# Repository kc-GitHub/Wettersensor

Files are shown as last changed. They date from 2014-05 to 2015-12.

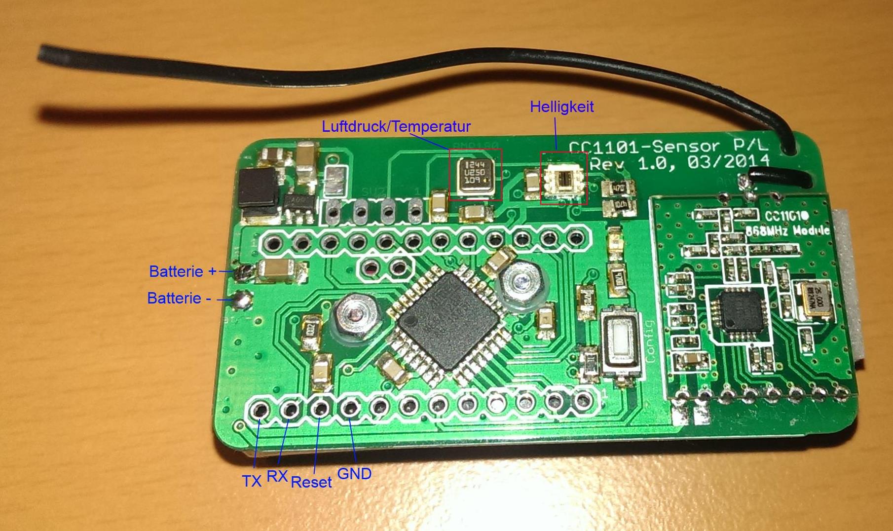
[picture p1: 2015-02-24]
Images/HB-UW-Sen-THPL-O_Overview_Rev_1.0.jpg

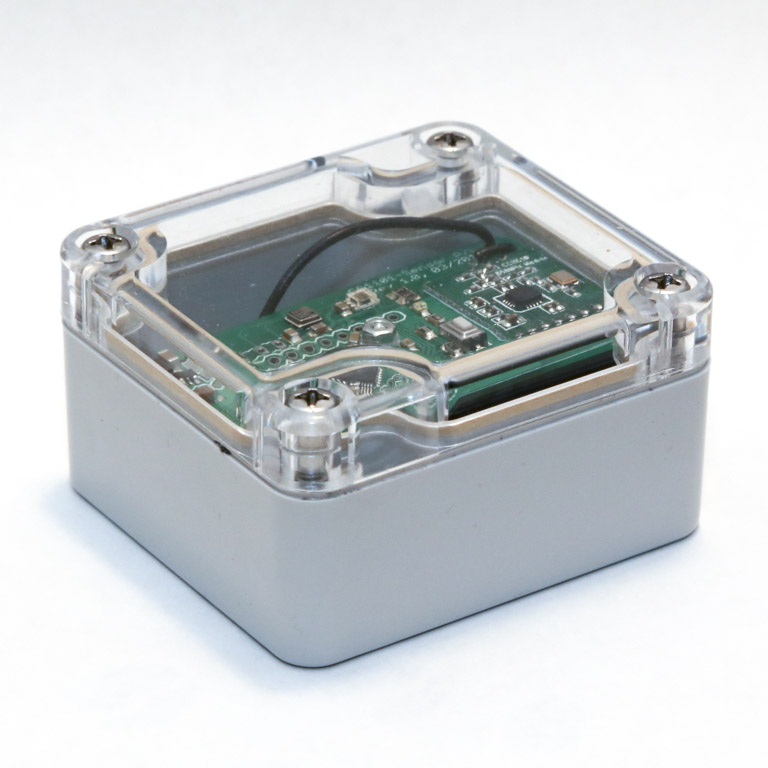
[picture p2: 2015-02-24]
Images/HB-UW-Sen-THPL-O.jpg

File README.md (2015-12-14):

Firmware for Univarsal Wettersensor
===================================

* http://www.fhemwiki.de/wiki/Universalsensor
* http://forum.fhem.de/index.php/topic,20620.0.html

#Changelog#

##Version 0.15 (Development)##
 * Improve / Fix debugging.
 * Fix [#16](/../../issues/16) so peering with HM-CC-RT-DN should stable now.
 * Add hysteresis for battery voltage measurement.
 * Experimental support for US-100 ultrasonic distance sensor (Do not use this experimental feature if you need the peering with HM-CC-RT-DN at this time)

##Version 0.14##
 * Fix millis() overflow bug. Now, the sensor stays in sleep mode after 49 days, so battery should not drained anymore
 * Battery voltage now measured with 1 digit only.

##Version 0.13 (Beta)##
 * Add new register:
   - transmitTryMax: How often should the sensor try to send data without ack.
   - lowBatLimit: Defined the battery voltage used for low battery detection.
   - ledMode: Switch the device LED on or off while sent out data.
   - altitude: Define the sensor-altitude for calculating the air pressure at sea level.

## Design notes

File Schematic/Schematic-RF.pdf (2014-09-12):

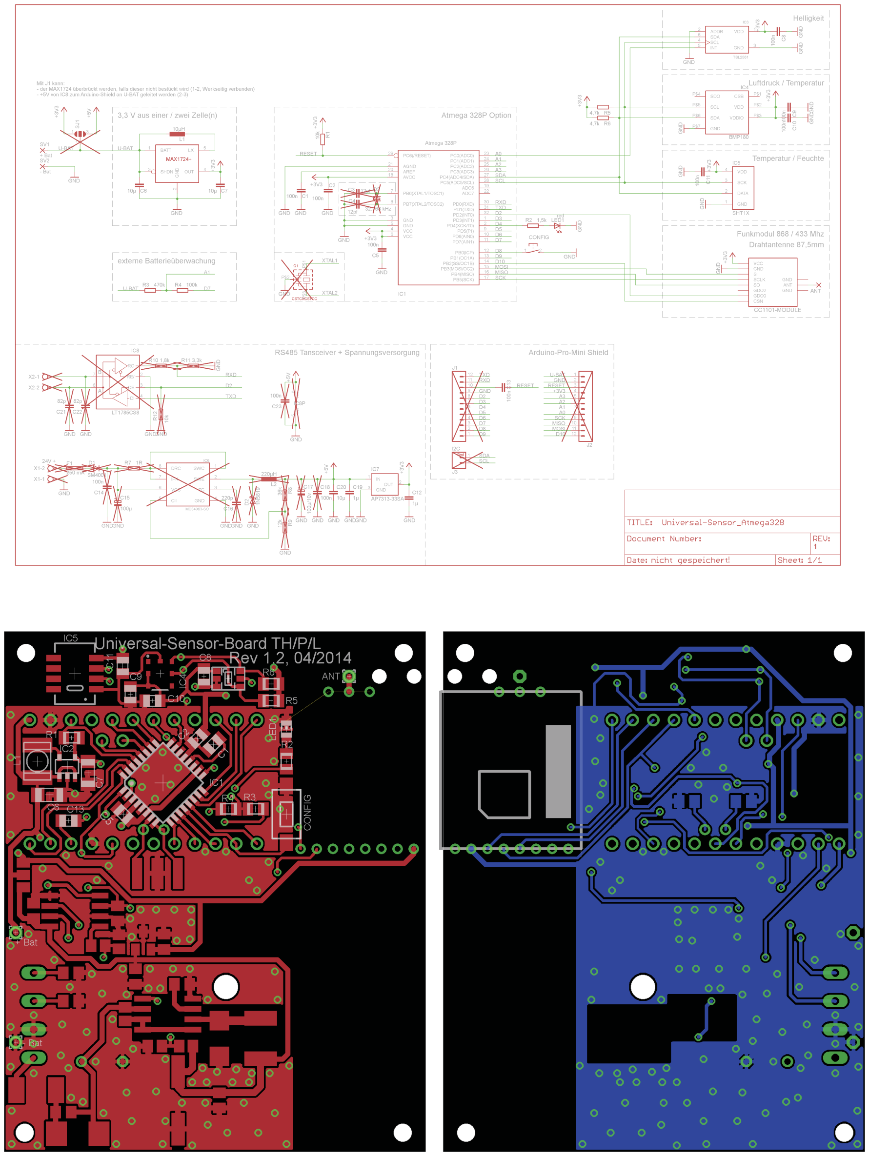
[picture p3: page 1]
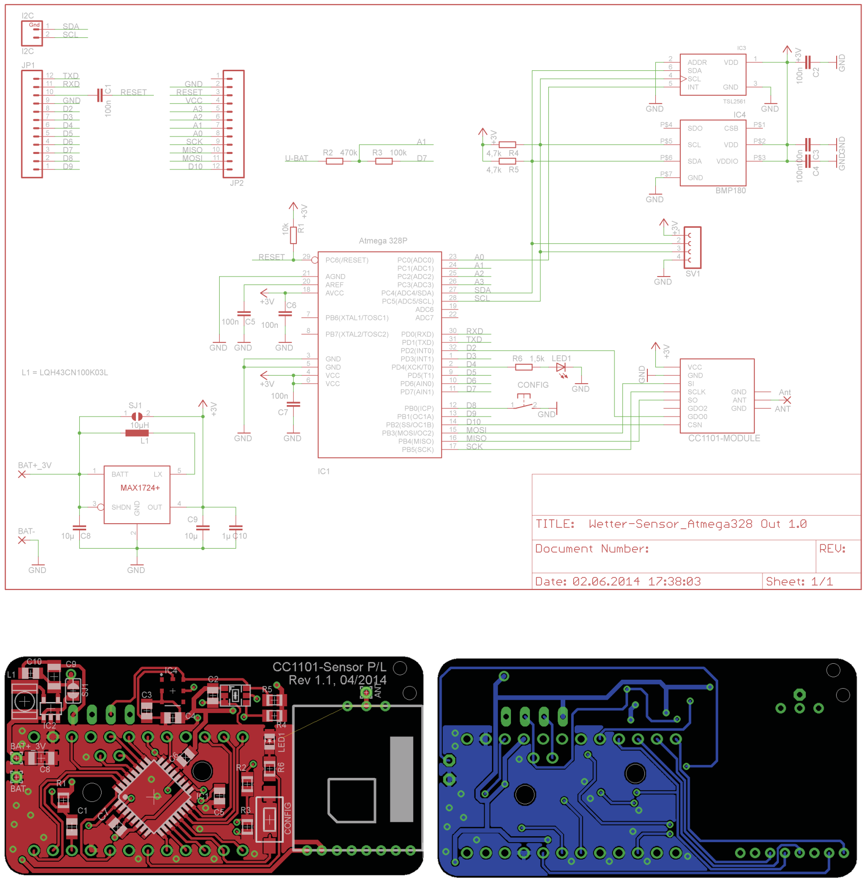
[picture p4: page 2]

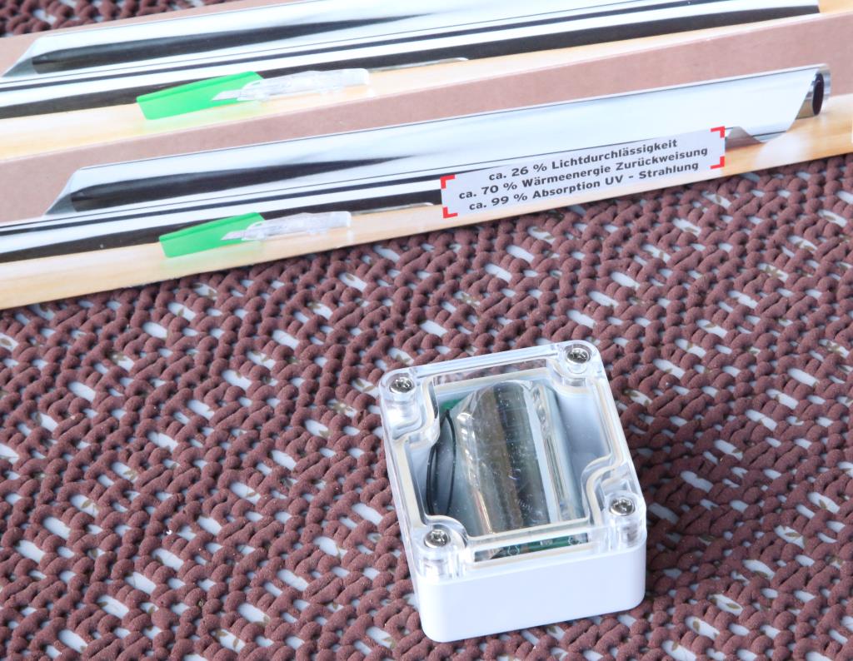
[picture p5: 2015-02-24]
Images/HB-UW-Sen-THPL-O_filter_foil.JPG

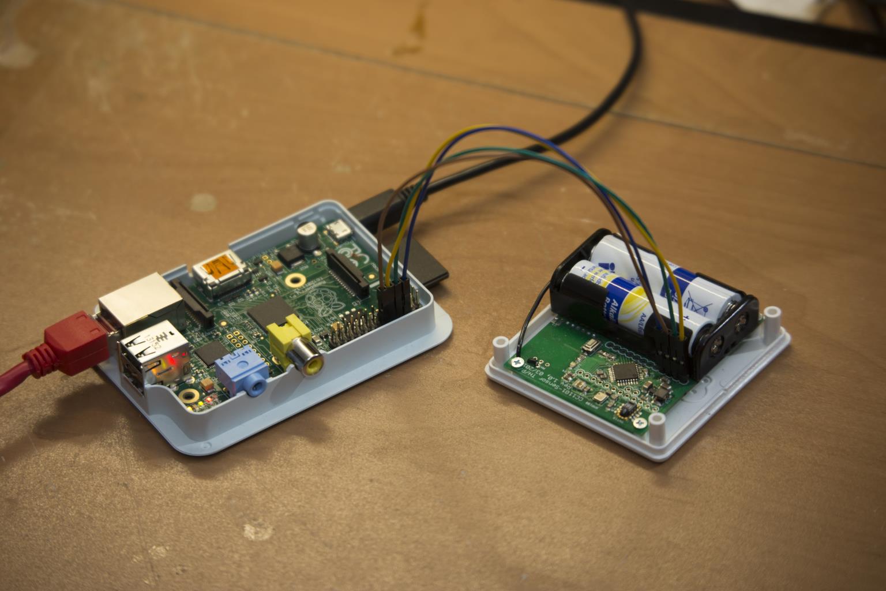
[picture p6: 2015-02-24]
Images/CC1101-Sensor Firmwareupdate mit dem Raspberry Pi.jpg

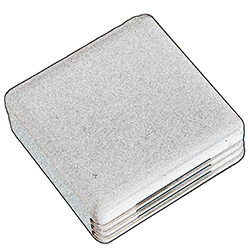
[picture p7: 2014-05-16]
Contrib/CCU/HB-UW-Sen-THPL_CCU-addon-src/www/config/img/devices/250/hb-uw-sen-thpl-i.png

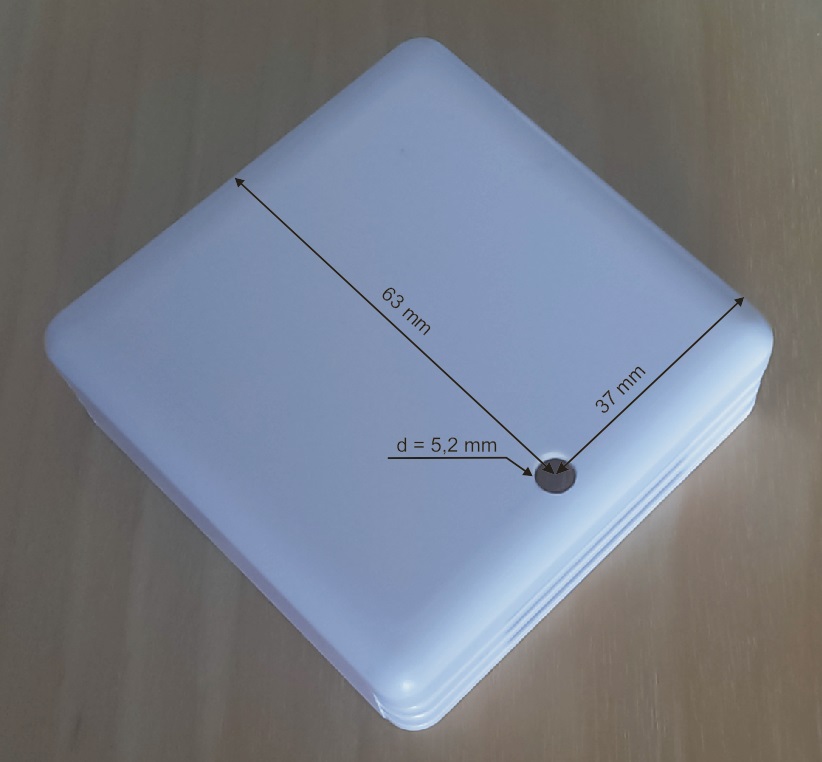
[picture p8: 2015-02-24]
Images/HB-UW-Sen-THPL-drill_dimension.jpg

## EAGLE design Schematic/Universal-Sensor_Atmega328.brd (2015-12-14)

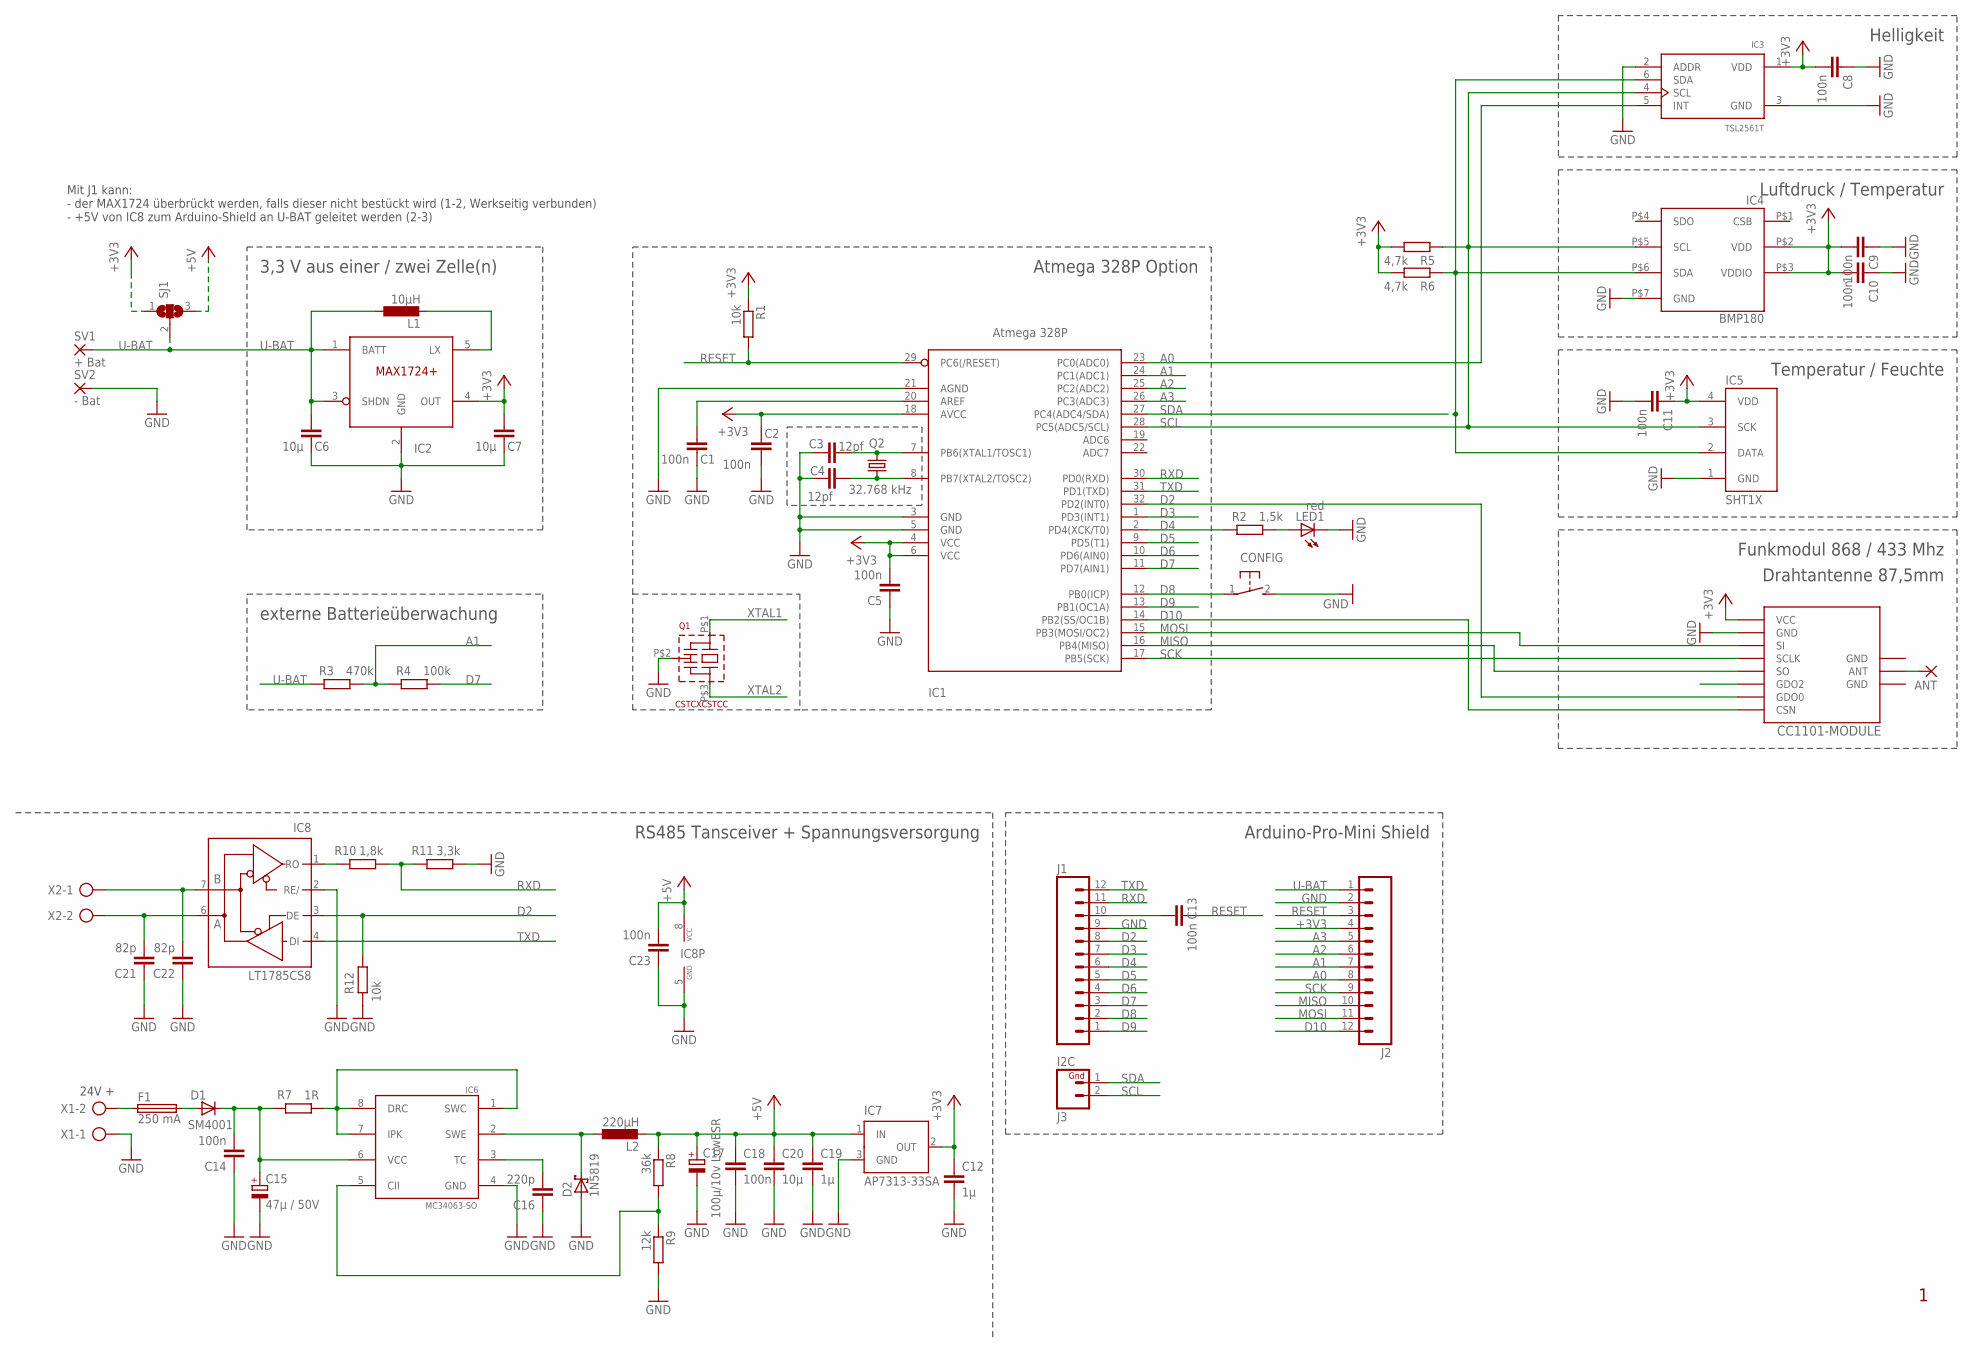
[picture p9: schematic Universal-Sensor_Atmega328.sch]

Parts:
ANT: 1,6/0,8
C1, C2, C5, C8, C9, C10, C11, C13, C18, C23: 100n; C0805
C3, C4: 12pf; C0805
C6, C7, C20: 10µ; C1206
C12, C19: 1µ; C0805
C14: 100n; C1206
C15: 47µ / 50V; E2,5-7
C16: 220p; C0805
C17: 100µ/10v LowESR; SMC_D
C21, C22: 82p; C0805
CC1101-MODULE: CC1101_WIRELES_MODULE
CONFIG: DTSM-3
D1: SM4001; MELF-MLL41
D2: 1N5819; SMB
F1: 250 mA; SMD-6,1X2,6
IC1: Atmega 328P; TQFP32-08
IC2: MAX1724; SOT23-5L
IC3: TSL2561T; TMB-6
IC4: BMP180; LGA-7
IC5: SHT1X
IC6: MC34063-SO; SO8
IC7: AP7313-33SA; SOT23
IC8: LT1785CS8; SO08
J1, J2: M12PTH; 1X12
J3: I2C; 1X02
L1: 10µH; L4532P
L2: 220µH; L5650M
LED1: red; CHIP-LED0805
Q1: CSTCXCSTCC; CSTCC
Q2: 32.768 kHz; TC38H
R1, R12: 10k; M0805
R2: 1,5k; M0805
R3: 470k; M0805
R4: 100k; M0805
R5, R6: 4,7k; M0805
R7: 1R; R0805
R8: 36k; R0805
R9: 12k; R0805
R10: 1,8k; R0805
R11: 3,3k; R0805
SJ1: SJ2W; SJ_2
SV1: + Bat; 1,6/0,9
SV2: - Bat; 1,6/0,9
X1, X2: AK550/2

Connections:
+3V3: C2.2, C5.2, C7.2, C8.2, C9.2, C10.2, C11.1, C12.1, CC1101-MODULE.VCC, IC1.4 (VCC), IC1.6 (VCC), IC1.18 (AVCC), IC2.4 (OUT), IC3.1 (VDD), IC4.P$2 (VDD), IC4.P$3 (VDDIO), IC5.4 (VDD), IC7.2 (OUT), J2.4, R1.1, R5.2, R6.2, SJ1.1
+5V: C17.+, C18.1, C19.1, C20.1, C23.2, IC7.1 (IN), IC8.8 (VCC), L2.2, R8.1, SJ1.3
A: C21.2, IC8.6 (A), X2.2
A0: IC1.23 (PC0(ADC0)), IC3.5 (INT), J2.8
A1: IC1.24 (PC1(ADC1)), J2.7, R3.2, R4.1
A2: IC1.25 (PC2(ADC2)), J2.6
A3: IC1.26 (PC3(ADC3)), J2.5
B: C22.2, IC8.7 (B), X2.1
D2: CC1101-MODULE.GDO0, IC1.32 (PD2(INT0)), IC8.3 (DE), J1.8, R12.2
D3: IC1.1 (PD3(INT1)), J1.7
D4: IC1.2 (PD4(XCK/T0)), J1.6, R2.1
D5: IC1.9 (PD5(T1)), J1.5
D6: IC1.10 (PD6(AIN0)), J1.4
D7: IC1.11 (PD7(AIN1)), J1.3, R4.2
D8: CONFIG.1, IC1.12 (PB0(ICP)), J1.2
D9: IC1.13 (PB1(OC1A)), J1.1
D10: CC1101-MODULE.CSN, IC1.14 (PB2(SS/OC1B)), J2.12
GND: C1.1, C2.1, C3.2, C4.2, C5.1, C6.1, C7.1, C8.1, C9.1, C10.1, C11.2, C12.2, C14.1, C15.-, C16.1, C17.-, C18.2, C19.2, C20.2, C21.1, C22.1, C23.1, CC1101-MODULE.GND@1 (GND), CC1101-MODULE.GND@2 (GND), CC1101-MODULE.GND@3 (GND), CONFIG.2, D2.A, IC1.3 (GND), IC1.5 (GND), IC1.21 (AGND), IC2.2 (GND), IC3.2 (ADDR), IC3.3 (GND), IC4.P$7 (GND), IC5.1 (GND), IC6.4 (GND), IC7.3 (GND), IC8.2 (RE/), IC8.5 (GND), J1.9, J2.2, LED1.C, Q1.P$2 (GND), R9.2, R11.1, R12.1, SV2.1, X1.1
MISO: CC1101-MODULE.SO, IC1.16 (PB4(MISO)), J2.10
MOSI: CC1101-MODULE.SI, IC1.15 (PB3(MOSI/OC2)), J2.11
unnamed: C13.2, J1.10
unnamed: IC2.5 (LX), L1.2
unnamed: LED1.A, R2.2
unnamed: ANT.1, CC1101-MODULE.ANT
unnamed: F1.1, X1.2
unnamed: IC8.1 (RO), R10.2
unnamed: C1.2, IC1.20 (AREF)
unnamed: D1.A, F1.2
unnamed: IC6.1 (SWC), IC6.7 (IPK), IC6.8 (DRC), R7.1
unnamed: C14.2, C15.+, D1.C, IC6.6 (VCC), R7.2
unnamed: IC6.5 (CII), R8.2, R9.1
unnamed: C16.2, IC6.3 (TC)
unnamed: D2.C, IC6.2 (SWE), L2.1
RESET: C13.1, IC1.29 (PC6(/RESET)), J2.3, R1.2
RXD: IC1.30 (PD0(RXD)), J1.11, R10.1, R11.2
SCK: CC1101-MODULE.SCLK, IC1.17 (PB5(SCK)), J2.9
SCL: IC1.28 (PC5(ADC5/SCL)), IC3.4 (SCL), IC4.P$5 (SCL), IC5.3 (SCK), J3.2, R5.1
SDA: IC1.27 (PC4(ADC4/SDA)), IC3.6 (SDA), IC4.P$6 (SDA), IC5.2 (DATA), J3.1, R6.1
TXD: IC1.31 (PD1(TXD)), IC8.4 (DI), J1.12
U-BAT: C6.2, IC2.1 (BATT), IC2.3 (SHDN), J2.1, L1.1, R3.1, SJ1.2, SV1.1
XTAL1: C3.1, IC1.7 (PB6(XTAL1/TOSC1)), Q1.P$1 (1), Q2.2
XTAL2: C4.1, IC1.8 (PB7(XTAL2/TOSC2)), Q1.P$3 (3), Q2.1

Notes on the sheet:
Mit J1 kann: - der MAX1724 überbrückt werden, falls dieser nicht bestückt wird (1-2, Werkseitig verbunden) - +5V von IC8 zum Arduino-Shield an U-BAT geleitet werden (2-3)
24V +
RS485 Tansceiver + Spannungsversorgung
3,3 V aus einer / zwei Zelle(n)
externe Batterieüberwachung
Arduino-Pro-Mini Shield
Atmega 328P Option
Helligkeit
Luftdruck / Temperatur
Temperatur / Feuchte
Funkmodul 868 / 433 Mhz
Drahtantenne 87,5mm
IC2

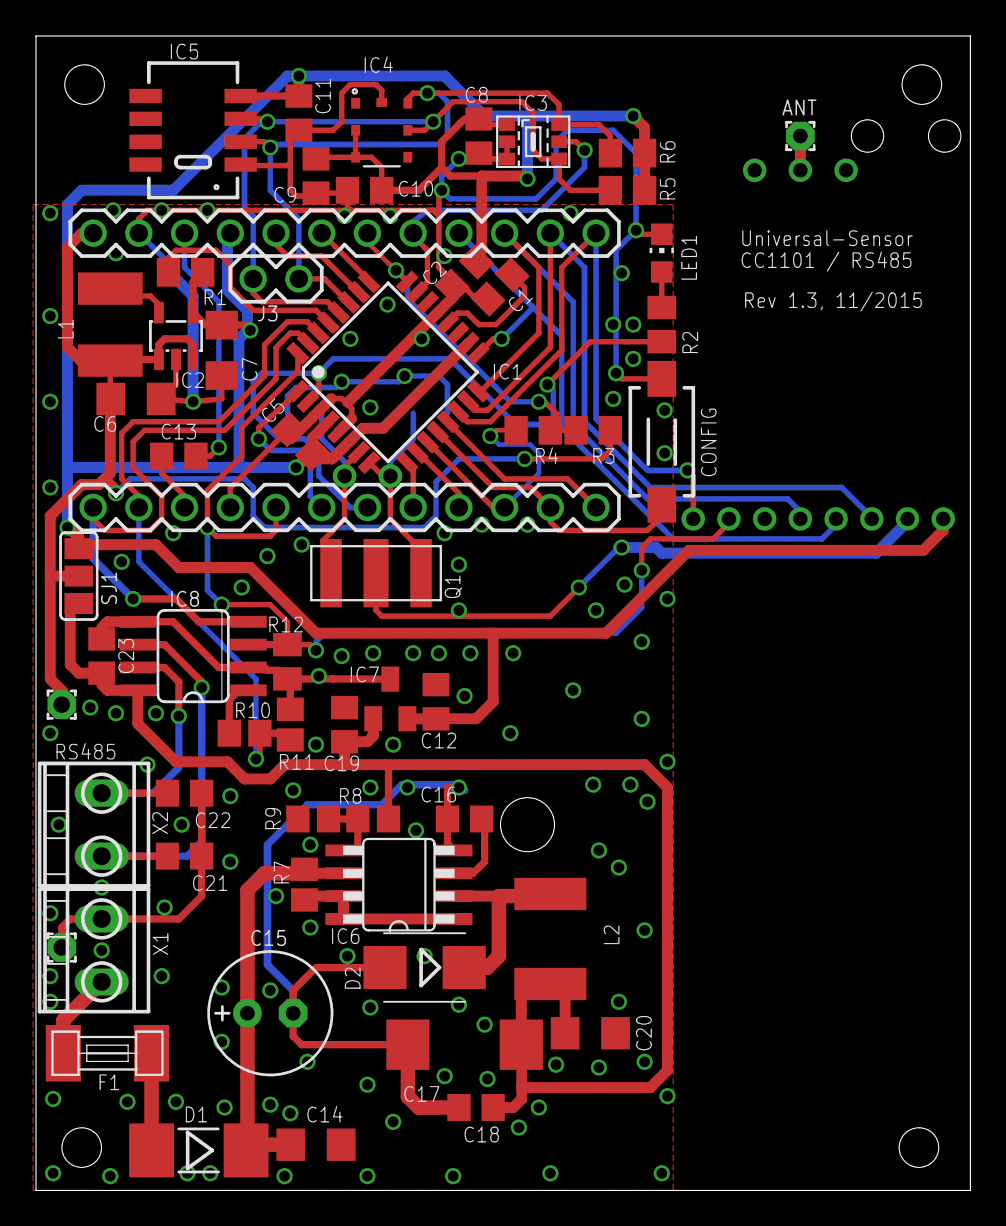
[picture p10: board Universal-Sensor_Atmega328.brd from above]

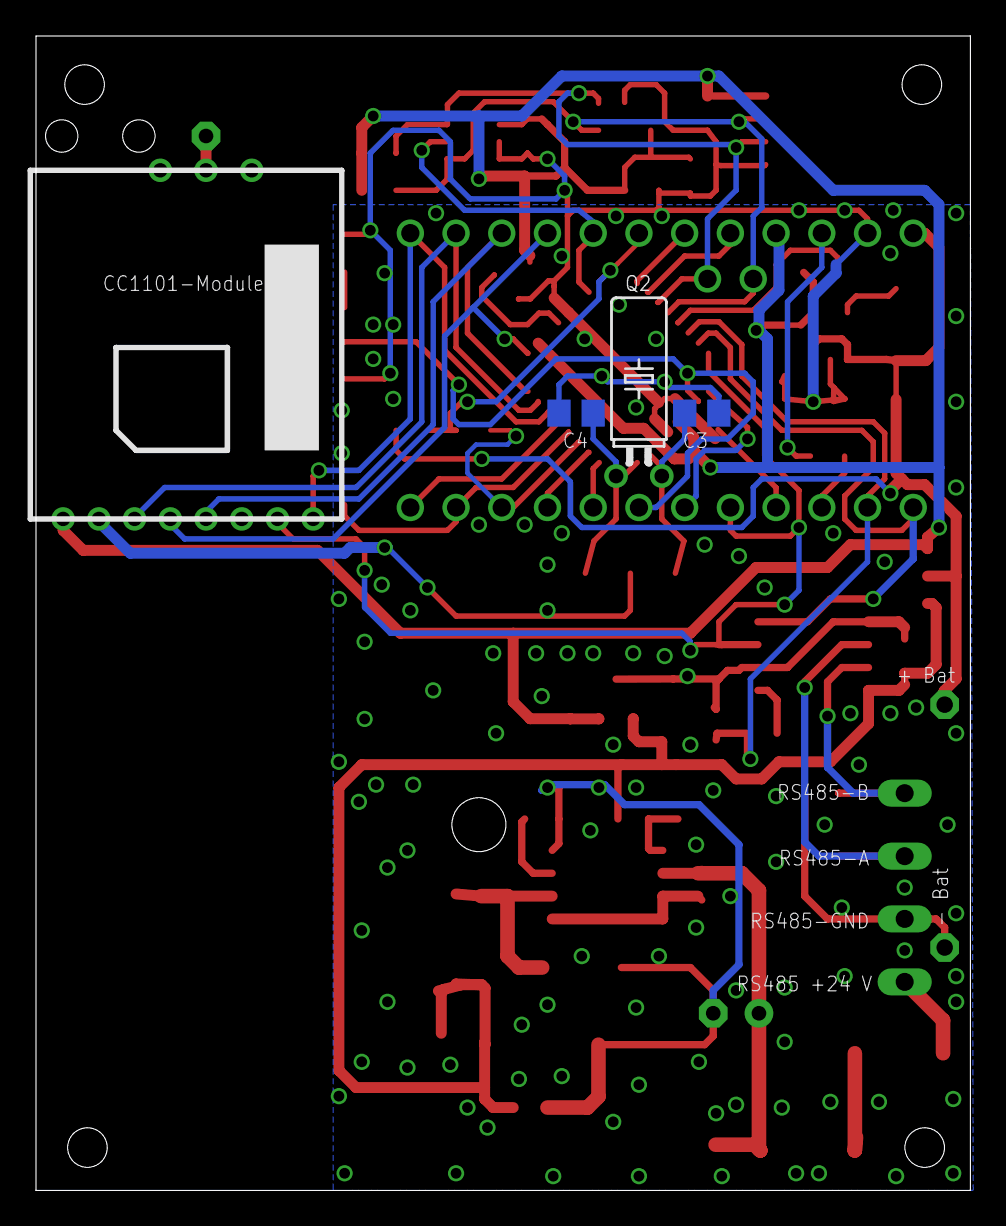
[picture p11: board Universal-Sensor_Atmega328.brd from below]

Board: 2 copper layers, 51.9 x 64.1 mm, 62 parts (4 on the bottom side), 42 nets.

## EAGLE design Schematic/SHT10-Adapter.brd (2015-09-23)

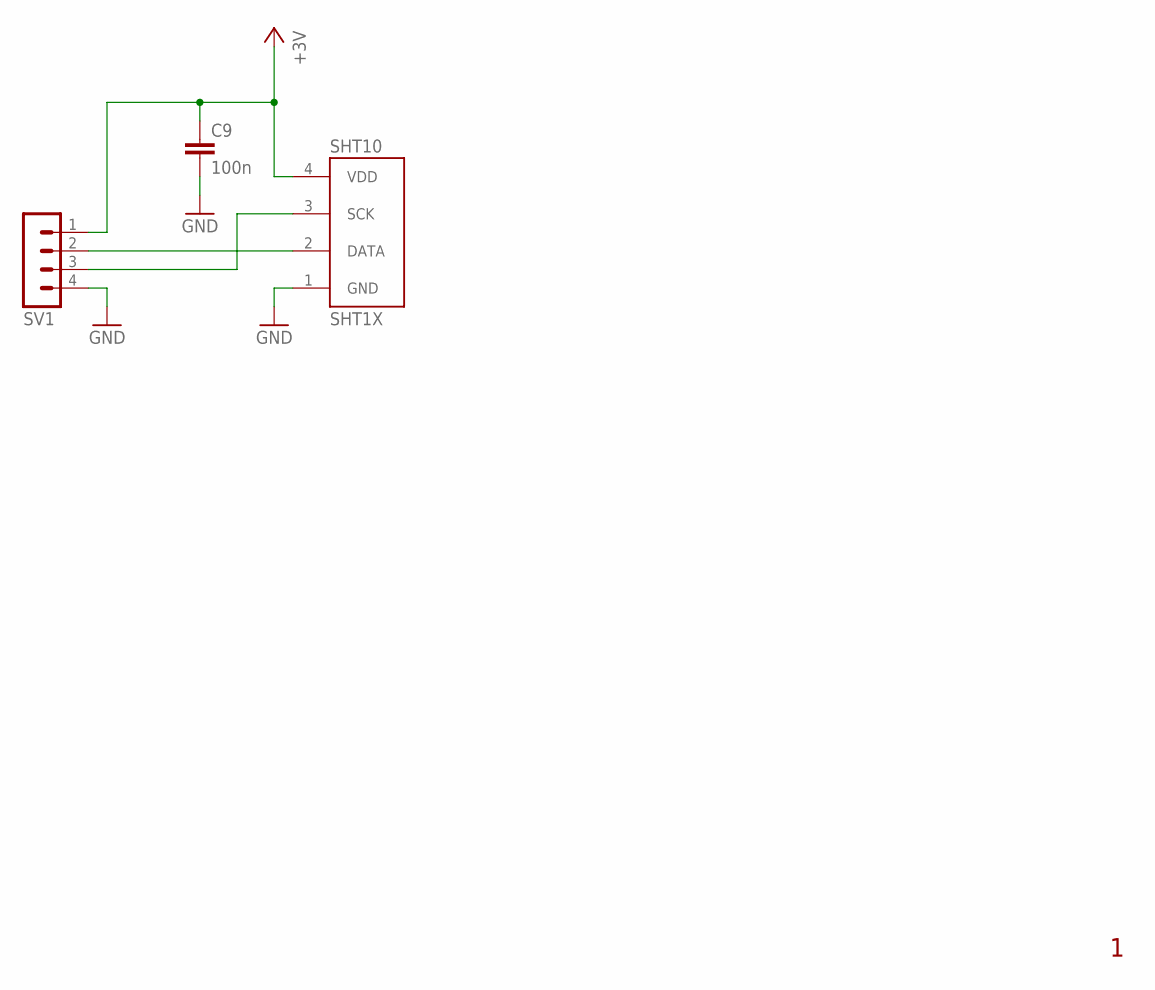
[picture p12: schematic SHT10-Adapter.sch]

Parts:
C9: 100n; C0805
SHT10: SHT1X
SV1: MA04-1

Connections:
GND: C9.2, SHT10.1 (GND), SV1.4
SCL: SHT10.3 (SCK), SV1.3
SDA: SHT10.2 (DATA), SV1.2
VCC: C9.1, SHT10.4 (VDD), SV1.1

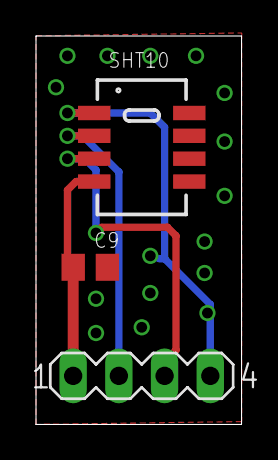
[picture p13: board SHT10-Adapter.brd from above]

Board: 2 copper layers, 11.4 x 21.6 mm, 3 parts (0 on the bottom side), 4 nets.

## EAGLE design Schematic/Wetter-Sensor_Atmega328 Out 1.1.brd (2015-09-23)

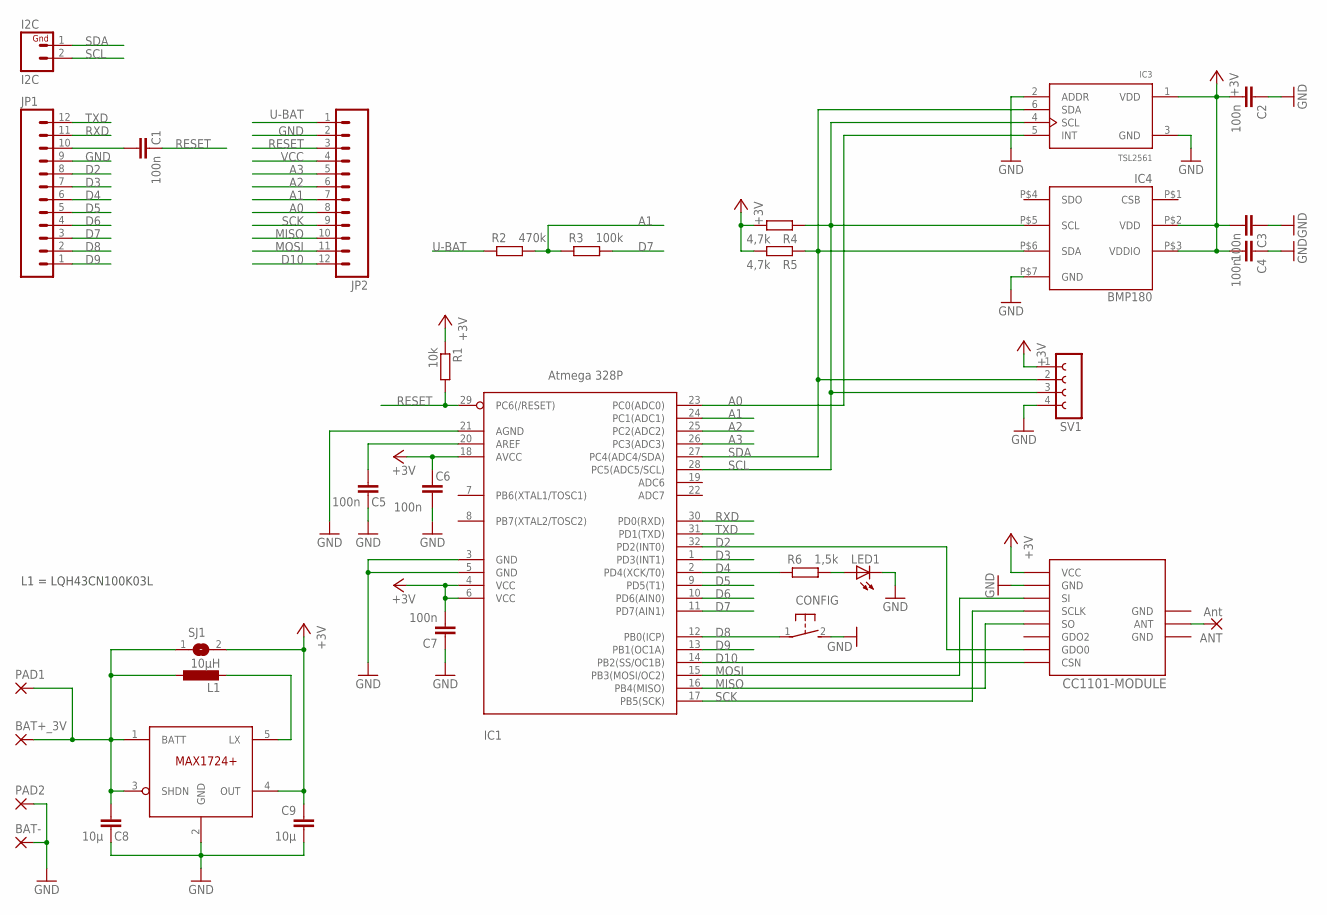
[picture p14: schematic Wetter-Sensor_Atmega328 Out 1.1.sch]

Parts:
ANT: Ant; 1,6/0,8
BAT+_3V: 1,6/0,9
BAT-: 1,6/0,9
C1, C2, C3, C4, C5, C6, C7: 100n; C0805
C8, C9: 10µ; C1206
CC1101-MODULE: CC1101_WIRELES_MODULE
CONFIG: DTSM-3
I2C: I2C; 1X02
IC1: Atmega 328P; TQFP32-08
IC2: MAX1724; SOT23-5L
IC3: TSL2561; TMB-6
IC4: BMP180; LGA-7
JP1, JP2: M12PTH; 1X12
L1: 10µH; L4532P
LED1: LEDCHIP-LED0805; CHIP-LED0805
PAD1, PAD2: SMD2; SMD1,27-2,54
R1: 10k; M0805
R2: 470k; M0805
R3: 100k; M0805
R4, R5: 4,7k; M0805
R6: 1,5k; M0805
SJ1: SJ
SV1: FE04-1

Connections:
A0: IC1.23 (PC0(ADC0)), IC3.5 (INT), JP2.8
A1: IC1.24 (PC1(ADC1)), JP2.7, R2.2, R3.1
A2: IC1.25 (PC2(ADC2)), JP2.6
A3: IC1.26 (PC3(ADC3)), JP2.5
D2: CC1101-MODULE.GDO0, IC1.32 (PD2(INT0)), JP1.8
D3: IC1.1 (PD3(INT1)), JP1.7
D4: IC1.2 (PD4(XCK/T0)), JP1.6, R6.1
D5: IC1.9 (PD5(T1)), JP1.5
D6: IC1.10 (PD6(AIN0)), JP1.4
D7: IC1.11 (PD7(AIN1)), JP1.3, R3.2
D8: CONFIG.1, IC1.12 (PB0(ICP)), JP1.2
D9: IC1.13 (PB1(OC1A)), JP1.1
D10: CC1101-MODULE.CSN, IC1.14 (PB2(SS/OC1B)), JP2.12
GND: BAT-.1, C2.1, C3.1, C4.1, C5.1, C6.1, C7.1, C8.1, C9.1, CC1101-MODULE.GND@1 (GND), CC1101-MODULE.GND@2 (GND), CC1101-MODULE.GND@3 (GND), CONFIG.2, IC1.3 (GND), IC1.5 (GND), IC1.21 (AGND), IC2.2 (GND), IC3.2 (ADDR), IC3.3 (GND), IC4.P$7 (GND), JP1.9, JP2.2, LED1.C, PAD2.1, SV1.4
MISO: CC1101-MODULE.SO, IC1.16 (PB4(MISO)), JP2.10
MOSI: CC1101-MODULE.SI, IC1.15 (PB3(MOSI/OC2)), JP2.11
unnamed: C1.2, JP1.10
unnamed: IC2.5 (LX), L1.2
unnamed: LED1.A, R6.2
unnamed: ANT.1, CC1101-MODULE.ANT
unnamed: C5.2, IC1.20 (AREF)
RESET: C1.1, IC1.29 (PC6(/RESET)), JP2.3, R1.2
RXD: IC1.30 (PD0(RXD)), JP1.11
SCK: CC1101-MODULE.SCLK, IC1.17 (PB5(SCK)), JP2.9
SCL: I2C.2, IC1.28 (PC5(ADC5/SCL)), IC3.4 (SCL), IC4.P$5 (SCL), R4.1, SV1.3
SDA: I2C.1, IC1.27 (PC4(ADC4/SDA)), IC3.6 (SDA), IC4.P$6 (SDA), R5.1, SV1.2
TXD: IC1.31 (PD1(TXD)), JP1.12
U-BAT: BAT+_3V.1, C8.2, IC2.1 (BATT), IC2.3 (SHDN), JP2.1, L1.1, PAD1.1, R2.1, SJ1.1
VCC: C2.2, C3.2, C4.2, C6.2, C7.2, C9.2, CC1101-MODULE.VCC, IC1.4 (VCC), IC1.6 (VCC), IC1.18 (AVCC), IC2.4 (OUT), IC3.1 (VDD), IC4.P$2 (VDD), IC4.P$3 (VDDIO), JP2.4, R1.1, R4.2, R5.2, SJ1.2, SV1.1

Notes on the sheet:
L1 = LQH43CN100K03L

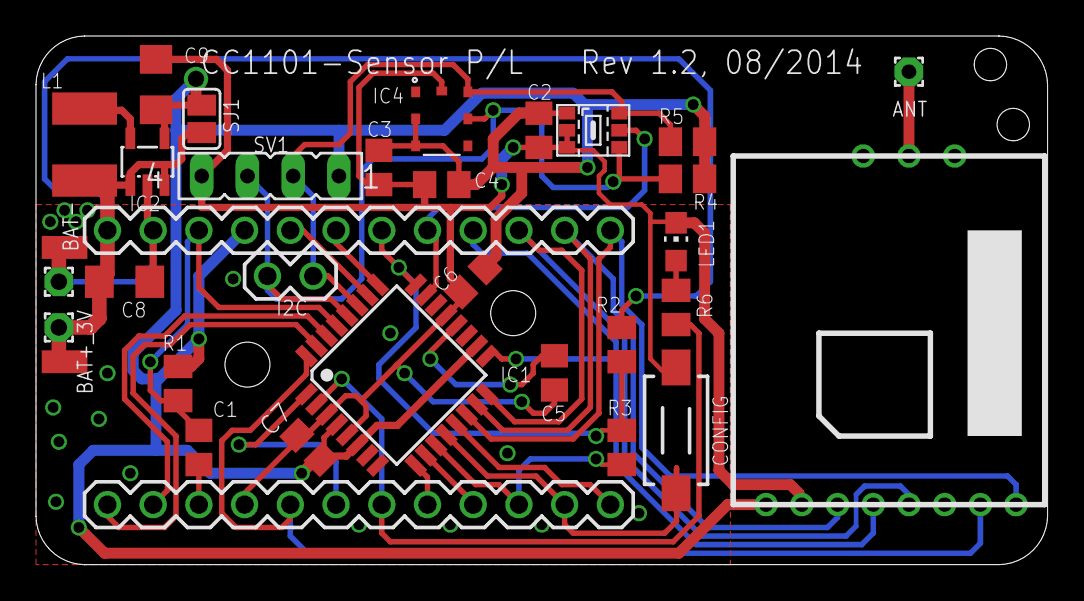
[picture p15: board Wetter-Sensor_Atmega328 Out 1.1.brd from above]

Board: 2 copper layers, 56.2 x 29.4 mm, 33 parts (0 on the bottom side), 29 nets.

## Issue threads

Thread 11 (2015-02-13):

Changing the behavior when reaching the set lowBatLimitTHPL

mr-p666, 2015-02-13:
Hej Dirk,

can you please change the behavior when reaching the set lowBatLimitTHPL.
At the moment it reports battery low when the configured value is reached and when the value is exceeded by 0.01 again, it reports battery ok again.
The power fluctuations cause a constant back and forth between the 'low' and 'ok' trigger as long as the fluctuations persist to this limit.
Is it possible to change only back to 'ok', when the current voltage value is at least 0,1V higher instead of current "everything higher than the threshold value"?

Thx a lot! :-)

kc-GitHub, 2015-03-06:
now there is a hysteresis of 0.2 v for reset battery low status after increasing battery voltage

Closed 2015-03-06.

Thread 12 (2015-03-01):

Fix wrong calculation with millis()

kc-GitHub, 2015-03-01:
The calculation of timeouts with millis() in the Lib is wrong
After 49 day if millis overflow, the device cant go in standby anymore. So the battery drained.

kc-GitHub, 2015-03-01:
Fixed

Closed 2015-03-01.

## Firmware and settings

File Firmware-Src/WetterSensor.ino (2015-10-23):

#include "WetterSensor.h"
#include "Register.h"															// configuration sheet

//- load library's --------------------------------------------------------------------------------------------------------
#include <Wire.h>																// i2c library, needed for bmp085 or bmp180
#include <TSL2561.h>
#include <Sensirion.h>
#include <BMP085.h>
#include <Buttons.h>															// remote buttons library
#include <Sensor_SHT10_BMP085_TSL2561.h>

// homematic communication
HM::s_jumptable jTbl[] = {														// jump table for HM communication
	// byte3, byte10, byte11, function to call									// 0xff means - any byte
	 { 0x11,  0x04,  0x00,    cmdReset },										// Reset message
	 { 0x01,  0xFF,  0x06,    cmdConfigChanged },								// Config end message
	 { 0x01,  0xFF,  0x0E,    cmdStatusRequest },
	 { 0x00 }
};

Buttons button[1];																// declare remote button object

Sensirion sht10;
BMP085 bmp085;
TSL2561 tsl2561;

Sensors_SHT10_BMP085_TSL2561 sensTHPL;

// main functions
void setup() {

	//millis overflow test
	//timer0_millis = 4294967295 - 666666;										// overflow reached in about 11 minutes and 7 seconds

	// We disable the Watchdog first
	wdt_disable();

	#ifdef SER_DBG
		Serial.begin(57600);													// serial setup
		Serial << F("Starting sketch...\n");									// ...and some information
		Serial << F("freeMem: ") << freeMem() << F(" byte") << F("\n");
	#endif

	#if USE_ADRESS_SECTION == 1
		getDataFromAddressSection(devParam, 1,  ADDRESS_SECTION_START + 0, 12);	// get device type (model-ID) and serial number from bootloader section at 0x7FF0 and 0x7FF2
		getDataFromAddressSection(devParam, 17, ADDRESS_SECTION_START + 12, 3);	// get device address stored in bootloader section at 0x7FFC

		Serial << F("Device type from Bootloader: "); pHex(&devParam[1],  2, SERIAL_DBG_PHEX_MODE_LF);
		Serial << F("Serial from Bootloader: ")     ; pHex(&devParam[3], 10, SERIAL_DBG_PHEX_MODE_LF);
		Serial << F("Addresse from Bootloader: ")   ; pHex(&devParam[17], 3, SERIAL_DBG_PHEX_MODE_LF);
	#else
		Serial << F("Device type from PROGMEM: "); pHex(&devParam[1],  2, SERIAL_DBG_PHEX_MODE_LF);
		Serial << F("Serial from PROGMEM: ")     ; pHex(&devParam[3], 10, SERIAL_DBG_PHEX_MODE_LF);
		Serial << F("Addresse from PROGMEM: ")   ; pHex(&devParam[17], 3, SERIAL_DBG_PHEX_MODE_LF);
	#endif

	hm.cc.config(10,11,12,13,2,0);												// CS, MOSI, MISO, SCK, GDO0, Interrupt

	// setup battery measurement
	hm.battery.config(
		BATTERY_MODE_EXTERNAL_MESSUREMENT, 7, 1, BATTERY_MEASSUREMENT_FACTOR, 900000	// battery measurement every 15 minutes
	);

	hm.init();																	// initialize the hm module

	button[0].regInHM(0, &hm);													// register buttons in HM per channel, handover HM class pointer
	button[0].config(8, NULL);													// configure button on specific pin and handover a function pointer to the main sketch

	sensTHPL.regInHM(1, &hm);													// register sensor class in hm
	sensTHPL.config(A4, A5, 0, &sht10, &bmp085, &tsl2561);						// data pin, clock pin and timing - 0 means HM calculated timing, every number above will taken in milliseconds

	byte rr = MCUSR;
	MCUSR =0;

	cmdConfigChanged(0, 0);

	// initialization done, we blink 3 times
	hm.statusLed.config(4, 4);													// configure the status led pin
	hm.statusLed.set(STATUSLED_BOTH, STATUSLED_MODE_BLINKFAST, 3);

	#ifdef US_100
		// Initialize Pins for US-100 Ultrasonic distance sensor
		pinMode(US_100_PIN_VCC,      OUTPUT);
		digitalWrite(US_100_PIN_VCC, LOW);										// US-100 Power (off)

		pinMode(US_100_PIN_TRIGGER,      OUTPUT);
		digitalWrite(US_100_PIN_TRIGGER, LOW);									// US-100 Trigger (off)

		pinMode(US_100_PIN_ECHO, INPUT);										// US-100 Echo as input pin

		pinMode(US_100_PIN_GND,       OUTPUT);
		digitalWrite(US_100_PIN_GND,  LOW);										// US-100 Power-GND (must be off every time)
	#endif

}

void getDataFromAddressSection(uint8_t *buffer, uint8_t bufferStartAddress, uint16_t sectionAddress, uint8_t dataLen) {
	for (unsigned char i = 0; i < dataLen; i++) {
		buffer[(i + bufferStartAddress)] = pgm_read_byte(sectionAddress + i);
	}
}

void getPgmSpaceData(uint8_t *buffer, uint16_t address, uint8_t len) {
	for (unsigned char i = 0; i < len; i++) {
		buffer[i] = pgm_read_byte(address+i);
	}
}

void loop() {
	hm.poll();																	// poll the HM communication
}

void cmdReset(uint8_t *data, uint8_t len) {
	#ifdef SER_DBG
		Serial << F("reset, data: "); pHex(data,len, SERIAL_DBG_PHEX_MODE_LF);
	#endif

	hm.send_ACK();																// send an ACK
	if (data[1] == 0) {
		hm.reset();
//		hm.resetWdt();
	}
}

void cmdConfigChanged(uint8_t *data, uint8_t len) {
	// low battery level
	uint8_t lowBatVoltage = regs.ch0.l0.lowBatLimit;
	lowBatVoltage = (lowBatVoltage < BATTERY_MIN_VOLTAGE) ? BATTERY_MIN_VOLTAGE : lowBatVoltage;
	lowBatVoltage = (lowBatVoltage > BATTERY_MAX_VOLTAGE) ? BATTERY_MAX_VOLTAGE : lowBatVoltage;
	hm.battery.setMinVoltage(lowBatVoltage);

	// led mode
	hm.setLedMode((regs.ch0.l0.ledMode) ? LED_MODE_EVERYTIME : LED_MODE_CONFIG);

	// power mode for HM device
//	hm.setPowerMode(POWER_MODE_SLEEP_WDT);
	hm.setPowerMode((regs.ch0.l0.burstRx) ? POWER_MODE_BURST : POWER_MODE_SLEEP_WDT);
//	hm.setPowerMode(POWER_MODE_ON);

	// set max transmit retry
	uint8_t transmDevTryMax = regs.ch0.l0.transmDevTryMax;
	transmDevTryMax = (transmDevTryMax < 1) ? 1 : transmDevTryMax;
	transmDevTryMax = (transmDevTryMax > 10) ? 10 : transmDevTryMax;
	dParm.maxRetr = transmDevTryMax;

	// set altitude
	int16_t altitude = regs.ch0.l0.altitude[1] | (regs.ch0.l0.altitude[0] << 8);
	altitude = (altitude < -500) ? -500 : altitude;
	altitude = (altitude > 10000) ? 10000 : altitude;
	sensTHPL.setAltitude(altitude);

	#ifdef SER_DBG
		Serial << F("Config changed. Data: "); pHex(data,len, SERIAL_DBG_PHEX_MODE_LEN | SERIAL_DBG_PHEX_MODE_LF);
		Serial << F("lowBatLimit: ") << regs.ch0.l0.lowBatLimit << F("\n");
		Serial << F("ledMode: ") << regs.ch0.l0.ledMode << F("\n");
		Serial << F("burstRx: ") << regs.ch0.l0.burstRx << F("\n");
		Serial << F("transmDevTryMax: ") << transmDevTryMax << F("\n");
		Serial << F("altitude: ") << altitude << F("\n");
	#endif
}

void cmdStatusRequest(uint8_t *data, uint8_t len) {
	Serial << F("status request, data: "); pHex(data,len, SERIAL_DBG_PHEX_MODE_LF);
	_delay_ms(50);
}

void HM_Remote_Event(uint8_t *data, uint8_t len) {
	Serial << F("remote event, data: "); pHex(data,len, SERIAL_DBG_PHEX_MODE_LF);
}

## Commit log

2014-04-10 add modifyed bootloader: Support for Blinking the led while flashing, handle watchdog resets correctly.
2014-04-12 extension for adding own device types for FHEM
2014-04-12 new Version 0.6 with own device type
2014-04-14 Version 0.7, fix value if no brightness sensor available
2014-04-18 add addon for CCU 1 or CCU 2 to use the sensor
2014-05-11 add schematic
2014-07-18 update schematic
2014-09-13 fix bug, so the sht10 now can messure temperaturs below 0 °C
2014-09-19 reduce "air pressure now send with 1 digit precision.
2014-10-02 add register for low battery limit, led mode
2014-10-03 add register transmitTryMax and altitude to calculate air pressure at sea level
2014-10-06 change min low battery voltage to 1.0 V, update xml-files for ccu, update firmware
2015-02-26 fix bugs, so the code compiles with the arduion ide 1.6.0
    [WetterSensor.ino]
2015-02-26 update battery measurement factor
2015-02-27 increase battery measuring intervall to 15 minutes
2015-03-03 Fix / Rework debugging
    [WetterSensor.ino]
2015-09-23 add Eagle files
    [SHT10-Adapter.brd, SHT10-Adapter.sch, Universal-Sensor_Atmega328.brd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]
2015-10-23 fix for USE_ADRESS_SECTION=0, add experimental support for US-100 ultra sonic distance sensor
    [WetterSensor.ino]
2015-12-14 update board file
    [Universal-Sensor_Atmega328.brd]

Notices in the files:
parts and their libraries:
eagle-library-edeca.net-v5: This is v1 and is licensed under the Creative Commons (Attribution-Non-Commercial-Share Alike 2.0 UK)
